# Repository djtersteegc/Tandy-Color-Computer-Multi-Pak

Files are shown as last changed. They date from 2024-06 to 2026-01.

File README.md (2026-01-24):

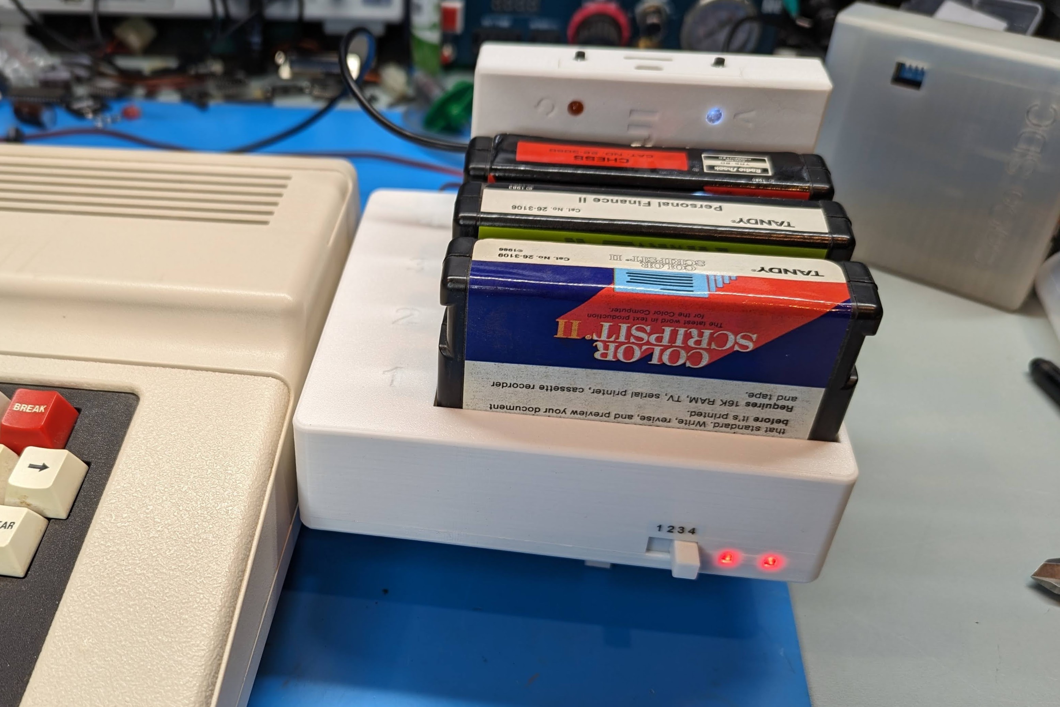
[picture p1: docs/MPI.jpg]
MPI


Inspired by the work of [TheLittleEngineers](https://github.com/TheLittleEngineers/CoCoDragon-MultiPakInterface-CC-Multi-Pak_Version_1.2), this is my respin of the Tandy 26-3024 Multi-Pak (MPI).  It's targeted at the DIY builder so the schematic is pretty much straight out of the Tandy service manual with all THT parts, minus the power section (more on that later).  The board size has been reduced as much as possible, and I added two LED's to indicate power to the MPI and Coco to minimize accidental unplugging when still powered up.  The cart slots are numbered one to four, front to back, like a real MPI, but are rotated 90 degrees so the cart labels face forward.  This was mainly done to better suit devices like the Coco Fujinet that have indicator LED's on the top of the cart and I saw Ed has done the same with his MPI variants.

For power you have a couple of different options.  You can power directly via an external 5V PSU via either a barrel jack, USB-C, or MicroUSB ports.  Or you can use a 7.5V PSU into the barrel jack and a pair of AMS1117 5V VRM's will split the power load between slots 1/2 and 3/4.  For +12V and -12V there are solder jumpers on the back to take that from the Coco1 cartridge port, but no options to provide those voltages on a Coco2 or 3.

The case is a kickstand design to save on filament costs and printing time, but does have a 35mm tall top cover to better support the carts. There are also two different top designs, one that is mostly open from the cart slots to the board, and another that is fully shrouded, but uses almost double the filament.  I personally haven't printed the latter option yet.

Schematic - https://djtersteegc.github.io/Tandy-Color-Computer-Multi-Pak/Tandy%20Color%20Computer%20Multi-Pak%20Schematic.pdf

# BOM

CSV - https://djtersteegc.github.io/Tandy-Color-Computer-Multi-Pak/Tandy%20Color%20Computer%20Multi-Pak%20BOM.csv

iBOM - https://djtersteegc.github.io/Tandy-Color-Computer-Multi-Pak/ibom.html

Google Sheet with some AliExpress links - https://docs.google.com/spreadsheets/d/16bxERXJ9wRitJPs6XrFosqCZR3fNDdbd6zl7ltthO44/edit?usp=sharing

I tend the buy most everything from China, either AliExpress of UTSource (for logic). For power, first figure out how you want to power the board and then pick the correct optional parts.  I'm assuming everyone will install the barrel jack, either for direct 5V or to feed 7.5V into the VRM's.

# Switch

The original switches I ordered from AliExpress had a 5mm high handle that was 3mm thick. That same listing is now for a 4mm high handle model which is only 2mm thick. Looking at other listings, even the ones that still show the thicker handle appear to be sending out the shorter and thinner handled model based on review pictures posted.

There are now two STL's for the switch depending on which model you get.  **MPI Switch.stl** is for the original taller/thicker one, and **MPI Switch Small Handle.stl** for the shorter/thinner one.

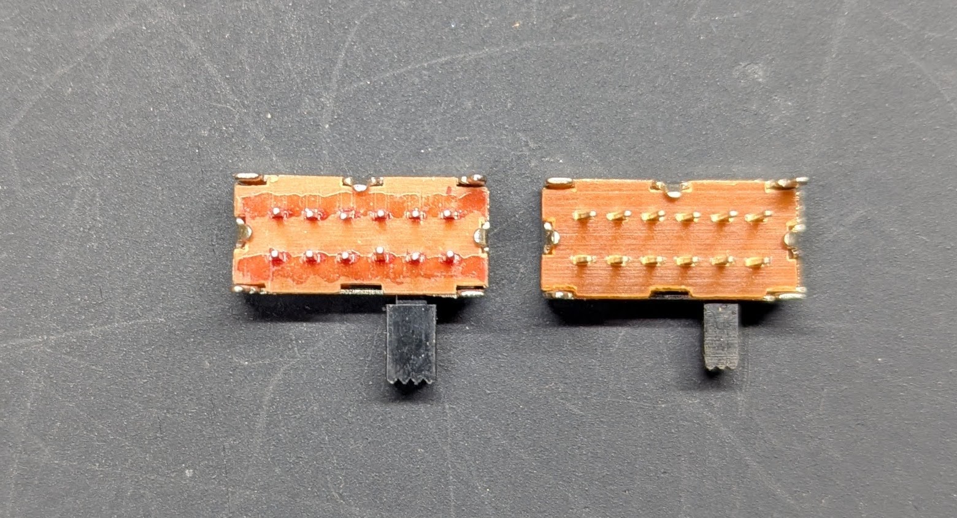
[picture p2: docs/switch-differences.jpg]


# PCB Assembly

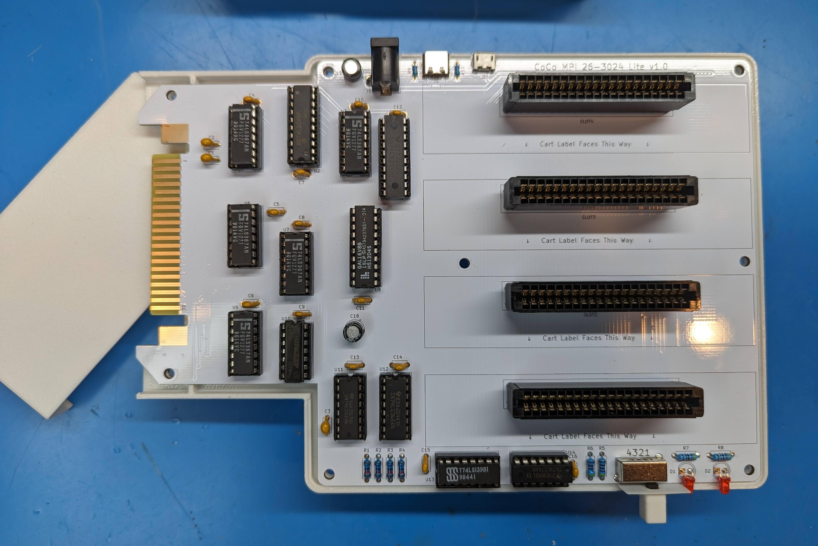
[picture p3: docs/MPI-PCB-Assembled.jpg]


# GAL Programming

U8 is a standard GAL16V8.  The programming file is available in the [GAL](GAL) directory. This should be the [newer version](https://retrocomputing.stackexchange.com/questions/477/the-tandy-trs-80-multipack-interface-mpi) that is compatible with the Coco3, but I'm unable to verify since I only have 1's and 2's to test with currently.

# 3D Printing the Case

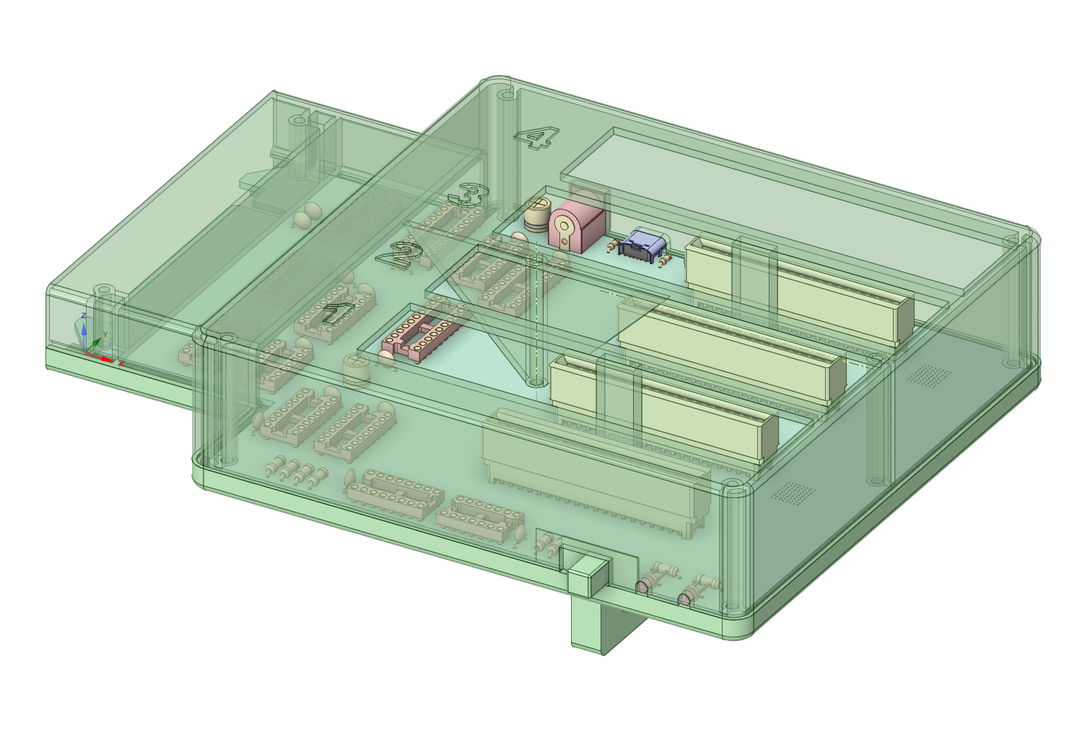
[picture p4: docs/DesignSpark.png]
DesignSpark


| Part | Filament |
| --- | --- |
| MPI Top.stl | 75g |
| MPI Bottom.stl | 62g |
| MPI Cart Top.stl | 20g |
| MPI Foot.stl | 12g |
| MPI Switch.stl | 1g |
| MPI Top Full Shroud.stl | 137g |

# Final Assembly

First screw the foot/kickstand to the bottom of the case with four [M3x10mm](https://www.aliexpress.us/item/2251832782301811.html) button head or countersunk head screws.

Then place the PCB, slide on the printed switch handle extender, place the cart top piece and then the larger top cover.  Flip over and assemble with eight M3x10mm to 14mm countersunk screws.

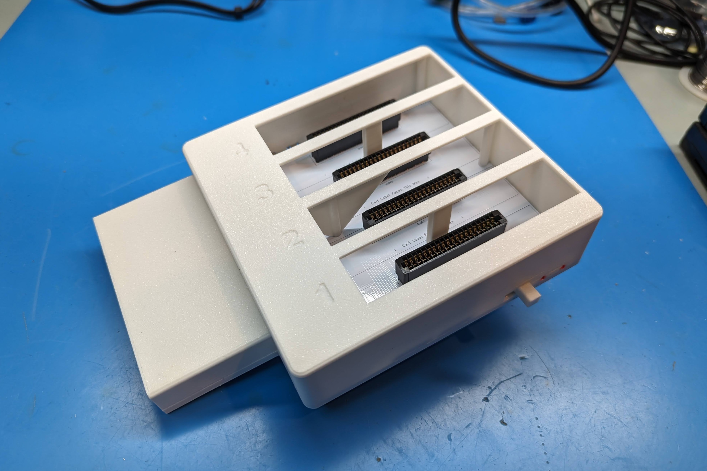
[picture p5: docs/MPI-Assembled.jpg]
MPI-Assembled


# Getting a Board to Build Your Own

Gerbers are available is you want to run your own batch. I would recommend ENIG (gold) finish since this is plugging into your cart edge connector. Otherwise if you are in the US hit my up on the Coco or FujiNet Discord (hideehoo is my username there) and if I have any extras I can drop one in the mail for $15 shipped.

# Versions

1.0 - Assembled and tested.  Initial batch of PCB's had produced had an incorrect switch footprint that required trimming of the locating tabs and the silkscreen with the slot numbering is reversed.  That has been corrected in the version 1.0 design files and gerbers in the intial upload to this repo.

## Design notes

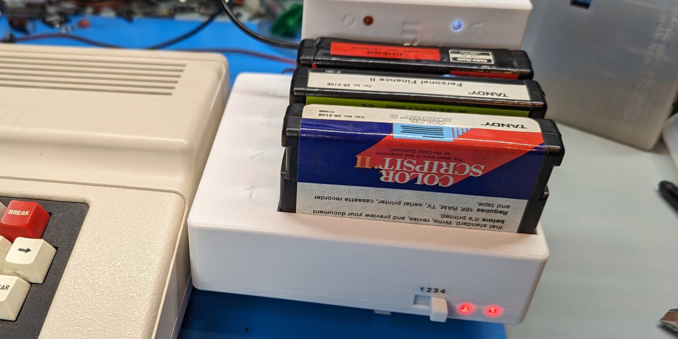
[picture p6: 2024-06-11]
docs/social.jpg

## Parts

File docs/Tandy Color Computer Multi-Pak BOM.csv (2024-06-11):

Reference | Value | Datasheet | Footprint | Qty | DNP
C1,C2 | 68pF | ~ | Capacitor_THT:C_Disc_D4.7mm_W2.5mm_P5.00mm | 2
C3 | 220pF | ~ | Capacitor_THT:C_Disc_D4.7mm_W2.5mm_P5.00mm | 1
C4,C5,C6,C7,C8,C9,C10,C11,C12,C13,C14,C15,C16 | 0.1uF | ~ | Capacitor_THT:C_Disc_D4.7mm_W2.5mm_P5.00mm | 13
C17,C20,C21,C22 | 22uf 10V | ~ | Capacitor_Tantalum_SMD:CP_EIA-3528-12_Kemet-T_Pad1.50x2.35mm_HandSolder | 4
C18,C19 | 100uF 16V | ~ | Capacitor_THT:CP_Radial_D6.3mm_P2.50mm | 2
D1,D2 | LED | ~ | LED_THT:LED_D3.0mm | 2
H1,H2,H3,H4,H5,H6,H7,H8 | MountingHole | ~ | MountingHole:MountingHole_3.2mm_M3 | 8
J1 | Barrel_Jack | ~ | Connector_BarrelJack:BarrelJack_Horizontal | 1
J2 | MICRO USB | ~ | RAHMB20AUETR:SWITCHCRAFT_RAHMB20AUETR | 1
J4 | USB-C |  | USB4125_GF_A:GCT_USB4125-GF-A_REVA2 | 1
JP1,JP2 | Plug / Reg | ~ | Jumper:SolderJumper-3_P1.3mm_Open_Pad1.0x1.5mm_NumberLabels | 2
JP3 | +12V | ~ | Jumper:SolderJumper-2_P1.3mm_Open_RoundedPad1.0x1.5mm | 1
JP4 | -12V | ~ | Jumper:SolderJumper-2_P1.3mm_Open_RoundedPad1.0x1.5mm | 1
P1 | PCB EDGE |  | Tersteeg:CoCo 40p PCB Cart Connector | 1
P2 | SLOT1 |  | Tersteeg:Coco 40p Cart Edge Connector | 1
P3 | SLOT2 |  | Tersteeg:Coco 40p Cart Edge Connector | 1
P4 | SLOT3 |  | Tersteeg:Coco 40p Cart Edge Connector | 1
P5 | SLOT4 |  | Tersteeg:Coco 40p Cart Edge Connector | 1
R1,R2,R3,R4 | 10K | ~ | Resistor_THT:R_Axial_DIN0207_L6.3mm_D2.5mm_P7.62mm_Horizontal | 4
R5,R6 | 4K7 | ~ | Resistor_THT:R_Axial_DIN0207_L6.3mm_D2.5mm_P7.62mm_Horizontal | 2
R7,R8 | 470R | ~ | Resistor_THT:R_Axial_DIN0207_L6.3mm_D2.5mm_P7.62mm_Horizontal | 2
R9,R10 | 5.1K | ~ | Resistor_THT:R_Axial_DIN0204_L3.6mm_D1.6mm_P5.08mm_Horizontal | 2
SW1 | ~ |  | Tersteeg:SK24D02VG4 2P4T Slide Switch | 1
U1,U3,U6,U7,U9 | 74LS367 | http://www.ti.com/lit/gpn/sn74LS367 | Package_DIP:DIP-16_W7.62mm_Socket | 5
U2 | 74LS245 | http://www.ti.com/lit/gpn/sn74LS245 | Package_DIP:DIP-20_W7.62mm_Socket | 1
U4 | 74LS374 | http://www.ti.com/lit/gpn/sn74LS374 | Package_DIP:DIP-20_W7.62mm_Socket | 1
U8 | GAL16V8 |  | Package_DIP:DIP-20_W7.62mm_Socket | 1
U10 | 74LS30 | http://www.ti.com/lit/gpn/sn74LS30 | Package_DIP:DIP-14_W7.62mm_Socket | 1
U11 | 74LS153 | http://www.ti.com/lit/gpn/sn74LS153 | Package_DIP:DIP-16_W7.62mm_Socket | 1
U12 | 74LS368 | http://www.ti.com/lit/gpn/sn74LS368 | Package_DIP:DIP-16_W7.62mm_Socket | 1
U13 | 74LS139 | http://www.ti.com/lit/ds/symlink/sn74ls139a.pdf | Package_DIP:DIP-16_W7.62mm_Socket | 1
U14 | 74LS74 | 74xx/74hc_hct74.pdf | Package_DIP:DIP-14_W7.62mm_Socket | 1
U15,U16 | AMS1117-5.0 | http://www.advanced-monolithic.com/pdf/ds1117.pdf | Tersteeg:SOT-223-3_TabPin2_Ext_Thermal | 2

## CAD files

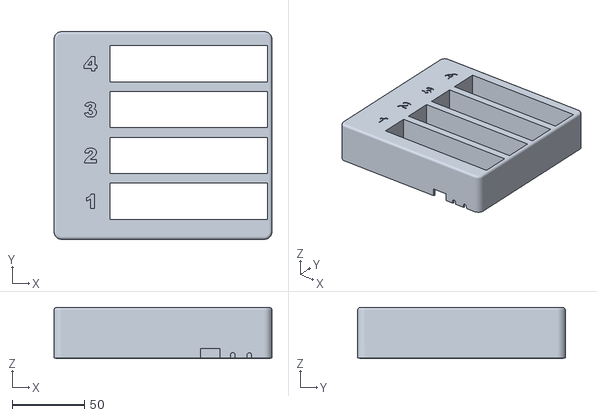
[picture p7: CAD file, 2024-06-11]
3D/STL/MPI Top Full Shroud.stl
150.9 x 143.9 x 35.6

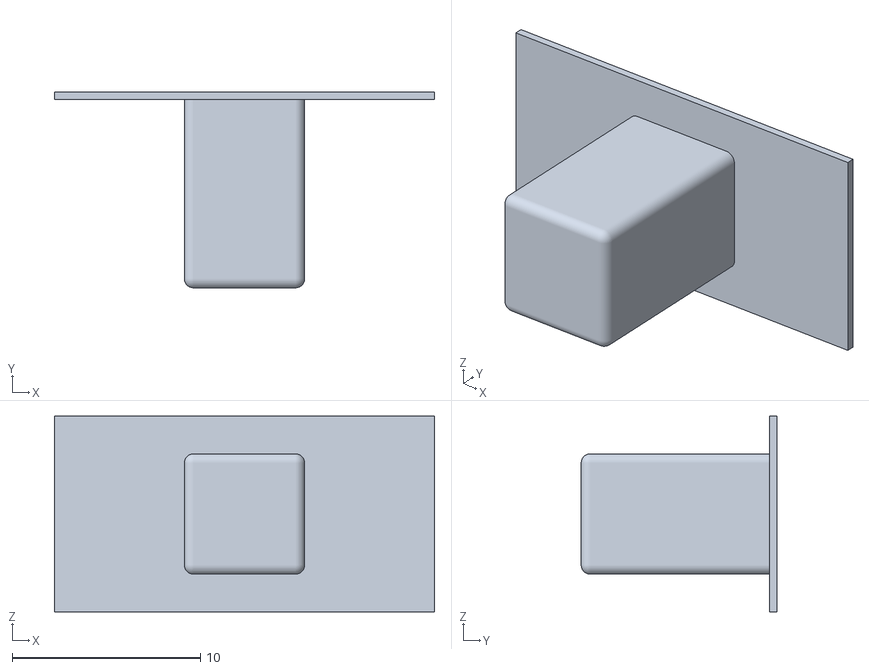
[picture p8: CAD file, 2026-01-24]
3D/STL/MPI Switch Small Handle.stl
20.2 x 10.4 x 10.4

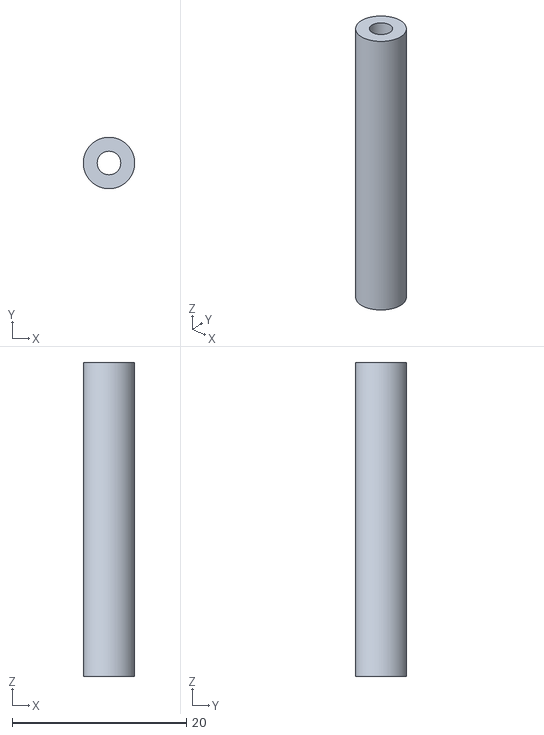
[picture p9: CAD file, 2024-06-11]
3D/STL/M3 x 38mm Standoff.stl
5.90 x 5.90 x 36.0

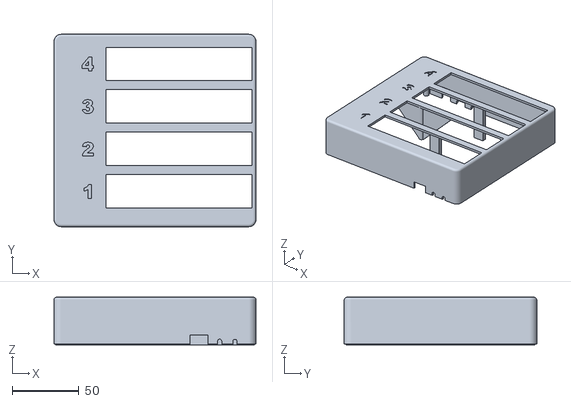
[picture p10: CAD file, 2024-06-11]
3D/STL/MPI Top.stl
150.9 x 143.9 x 35.6

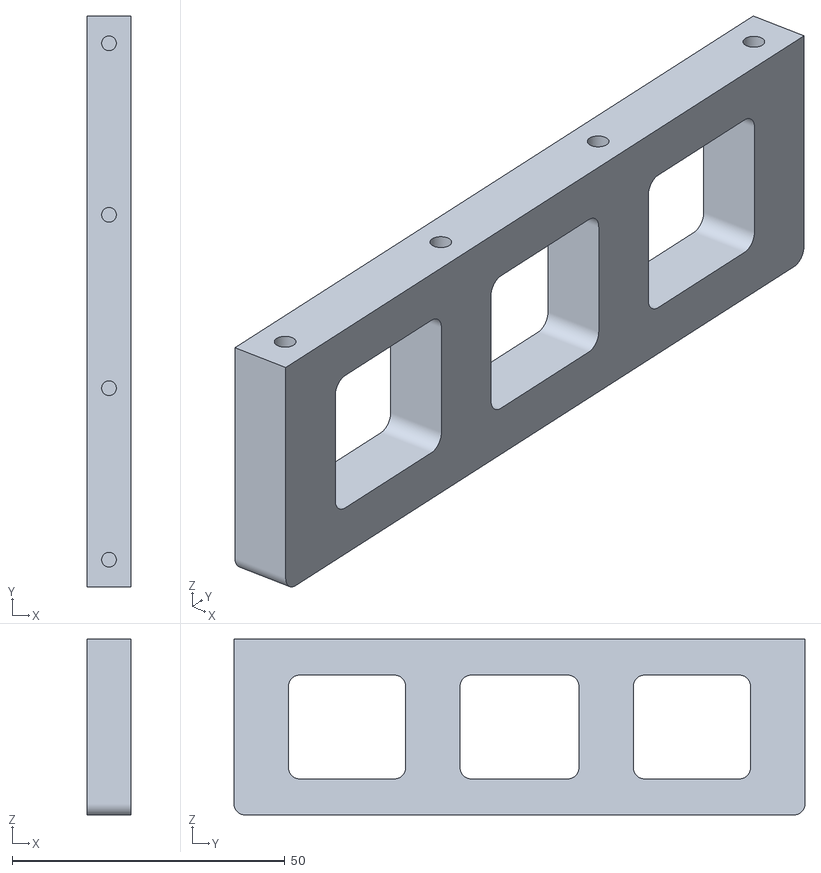
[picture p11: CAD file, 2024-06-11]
3D/STL/MPI Foot.stl
8.00 x 104.6 x 32.2

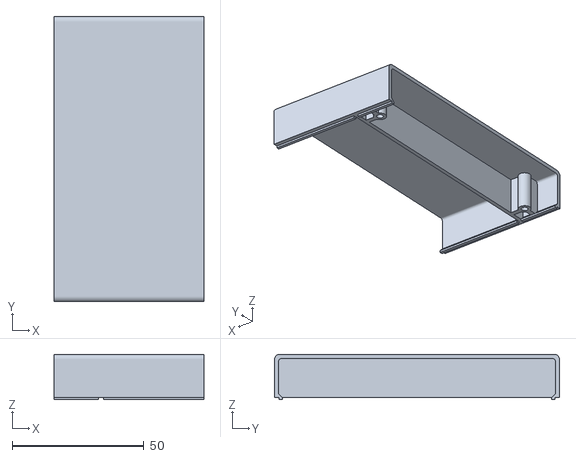
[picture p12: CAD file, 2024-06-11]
3D/STL/MPI Cart Top.stl
56.8 x 108.0 x 17.2

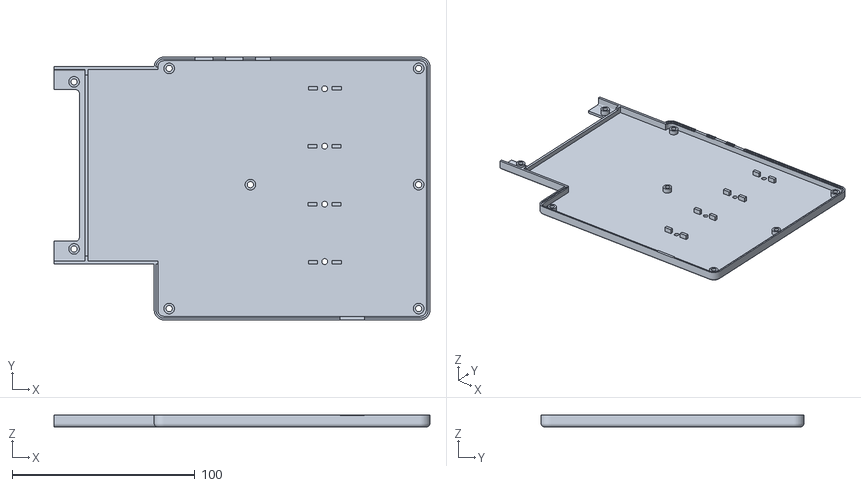
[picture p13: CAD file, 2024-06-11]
3D/STL/MPI Bottom.stl
205.8 x 143.9 x 6.60

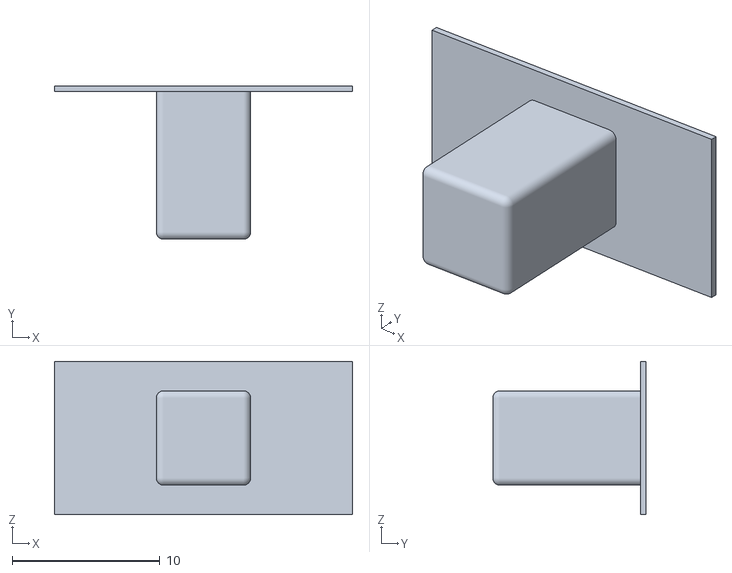
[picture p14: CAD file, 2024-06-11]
3D/STL/MPI Switch.stl
20.2 x 10.4 x 10.4

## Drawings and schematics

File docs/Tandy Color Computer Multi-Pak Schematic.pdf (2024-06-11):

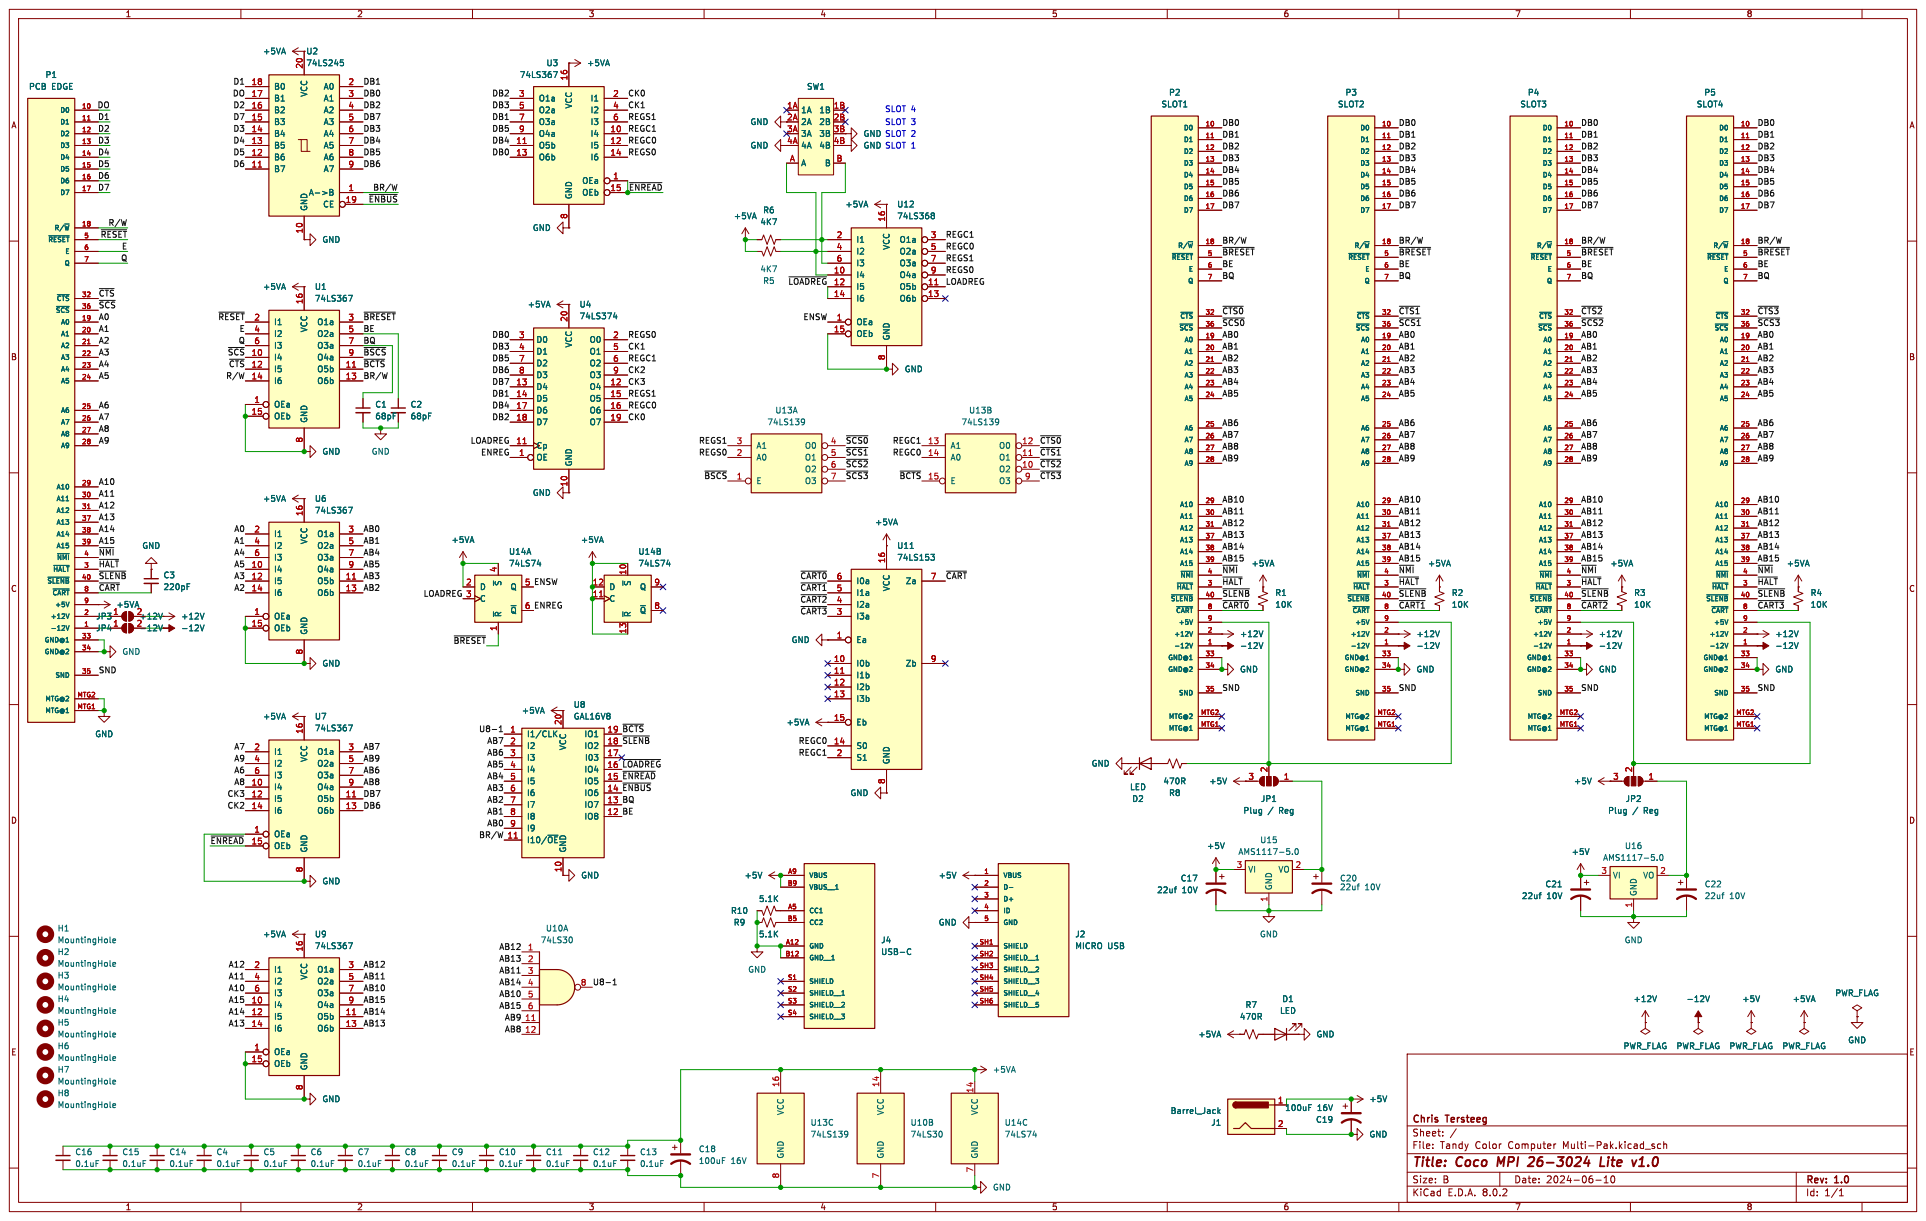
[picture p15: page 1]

~{CTS0} SLOT 2 SLOT 1 SLOT 3 SLOT 4

H2 MountingHole H5 MountingHole H1 MountingHole H3 MountingHole H4 MountingHole

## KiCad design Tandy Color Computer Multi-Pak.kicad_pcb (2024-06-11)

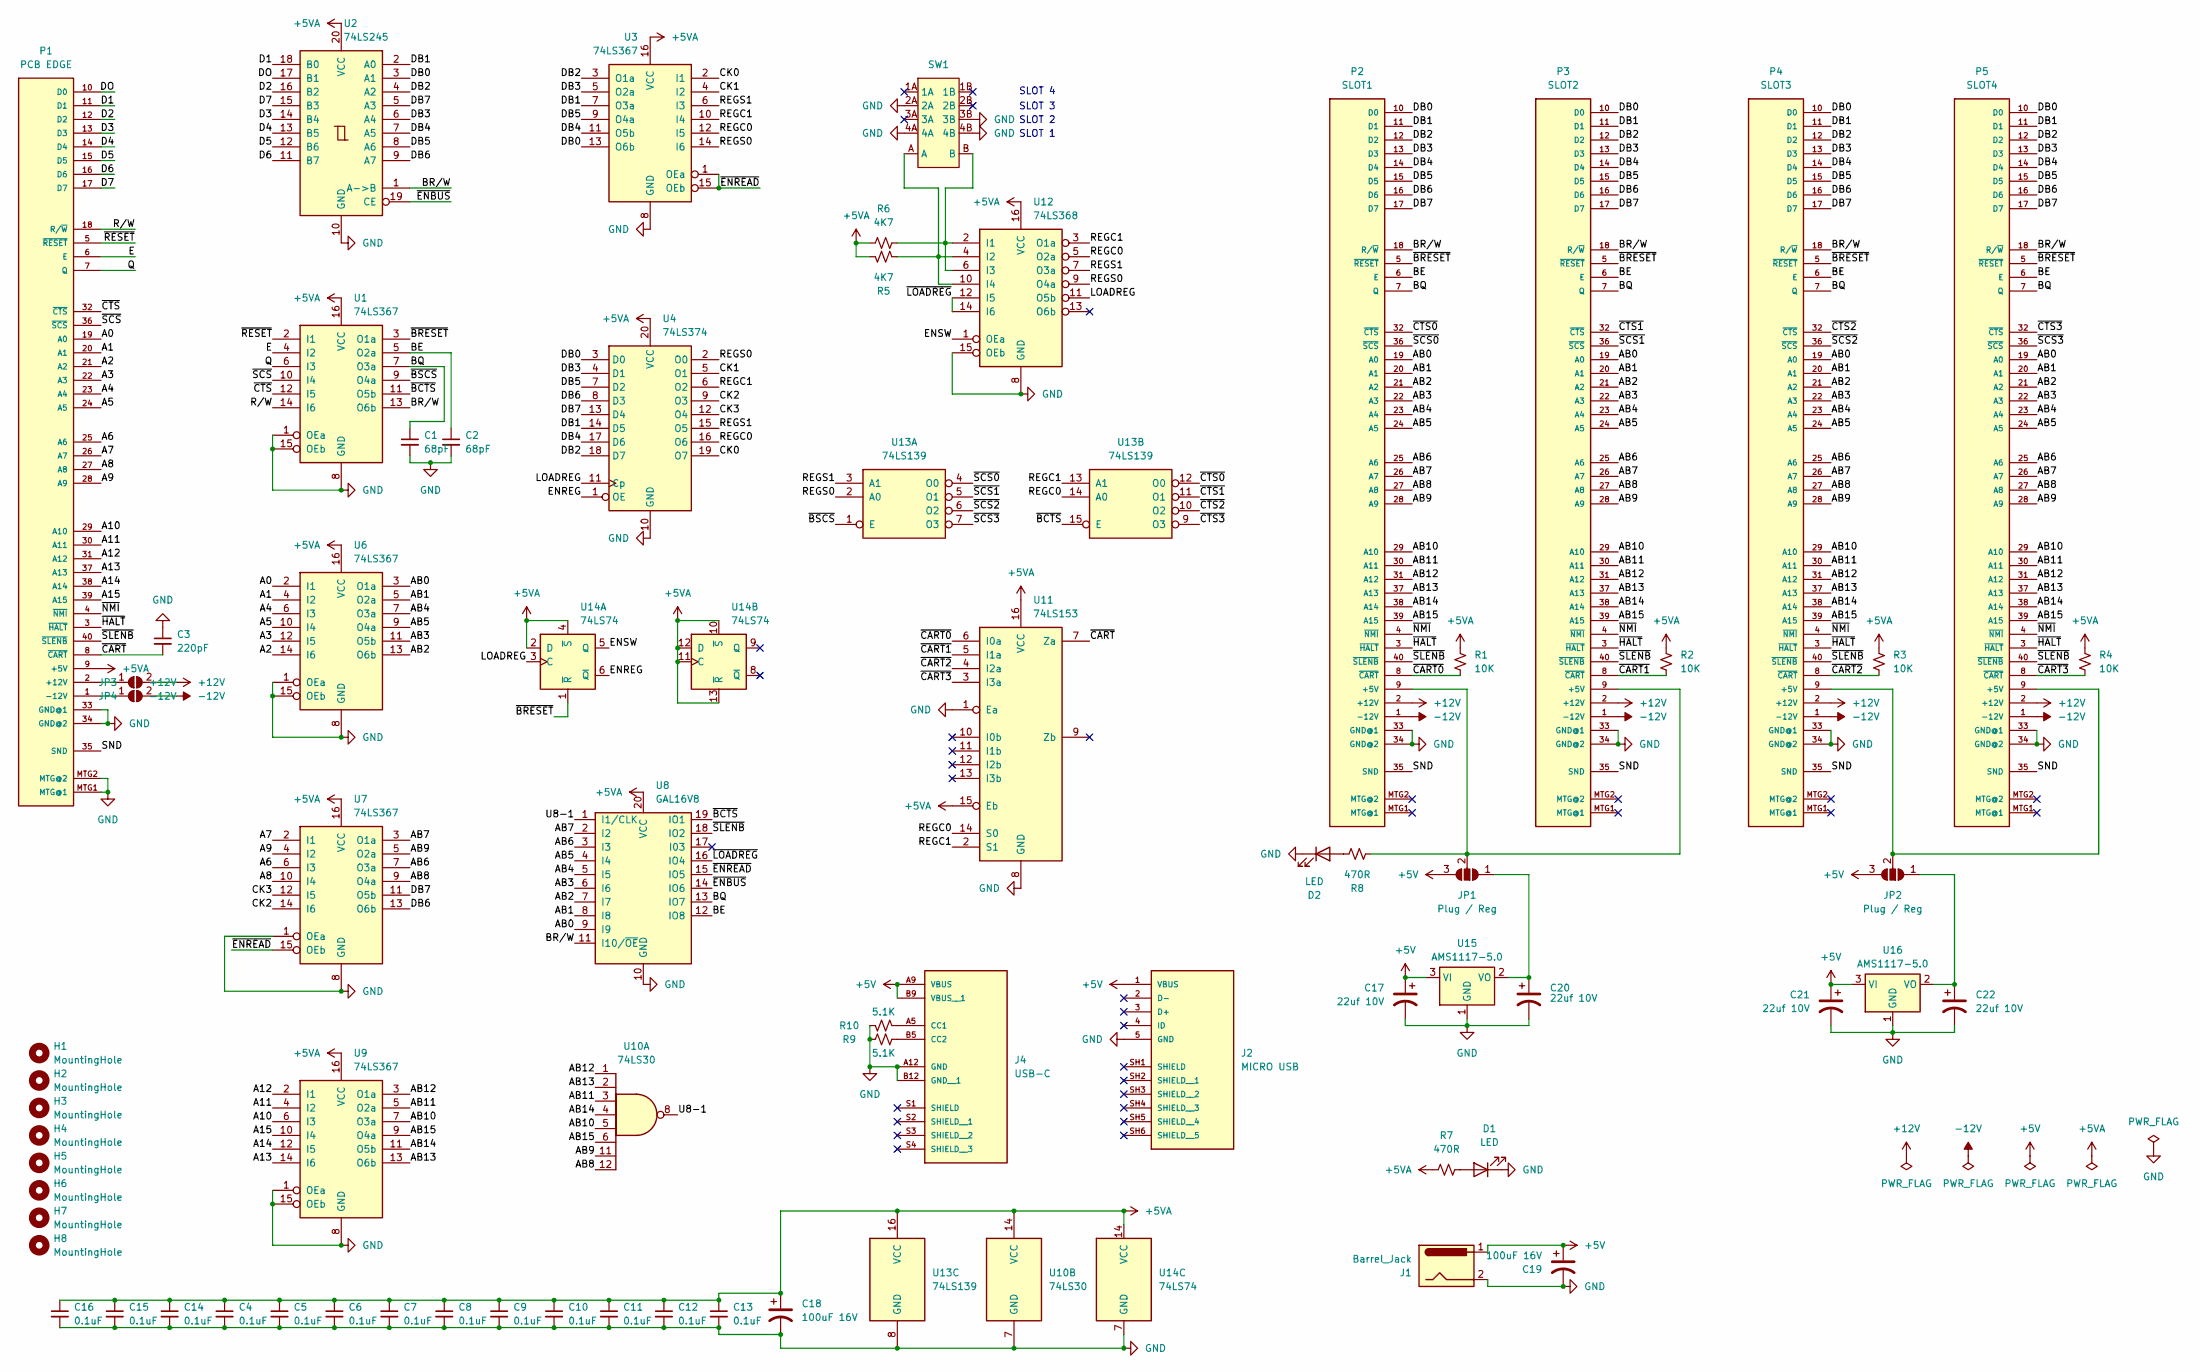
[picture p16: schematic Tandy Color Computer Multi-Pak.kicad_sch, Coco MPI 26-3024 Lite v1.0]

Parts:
C1, C2: 68pF; C_Disc_D4.7mm_W2.5mm_P5.00mm
C3: 220pF; C_Disc_D4.7mm_W2.5mm_P5.00mm
C4, C5, C6, C7, C8, C9, C10, C11, C12, C13, C14, C15, C16: 0.1uF; C_Disc_D4.7mm_W2.5mm_P5.00mm
C17, C20, C21, C22: 22uf 10V; CP_EIA-3528-12_Kemet-T_Pad1.50x2.35mm_HandSolder
C18, C19: 100uF 16V; CP_Radial_D6.3mm_P2.50mm
D1, D2: LED; LED_D3.0mm
H1, H2, H3, H4, H5, H6, H7, H8: MountingHole; MountingHole_3.2mm_M3
J1: Barrel_Jack; BarrelJack_Horizontal
J2: MICRO USB; SWITCHCRAFT_RAHMB20AUETR; PARTREV A
J4: USB-C; GCT_USB4125-GF-A_REVA2; PARTREV Rev A2
JP1, JP2: Plug / Reg; SolderJumper-3_P1.3mm_Open_Pad1.0x1.5mm_NumberLabels
JP3: +12V; SolderJumper-2_P1.3mm_Open_RoundedPad1.0x1.5mm
JP4: -12V; SolderJumper-2_P1.3mm_Open_RoundedPad1.0x1.5mm
P1: PCB EDGE; CoCo 40p PCB Cart Connector
P2: SLOT1; Coco 40p Cart Edge Connector
P3: SLOT2; Coco 40p Cart Edge Connector
P4: SLOT3; Coco 40p Cart Edge Connector
P5: SLOT4; Coco 40p Cart Edge Connector
R1, R2, R3, R4: 10K; R_Axial_DIN0207_L6.3mm_D2.5mm_P7.62mm_Horizontal
R5, R6: 4K7; R_Axial_DIN0207_L6.3mm_D2.5mm_P7.62mm_Horizontal
R7, R8: 470R; R_Axial_DIN0207_L6.3mm_D2.5mm_P7.62mm_Horizontal
R9, R10: 5.1K; R_Axial_DIN0204_L3.6mm_D1.6mm_P5.08mm_Horizontal
SW1: SK24D02VG4 2P4T Slide Switch
U1, U3, U6, U7, U9: 74LS367; DIP-16_W7.62mm_Socket
U2: 74LS245; DIP-20_W7.62mm_Socket
U4: 74LS374; DIP-20_W7.62mm_Socket
U8: GAL16V8; DIP-20_W7.62mm_Socket
U10: 74LS30; DIP-14_W7.62mm_Socket
U11: 74LS153; DIP-16_W7.62mm_Socket
U12: 74LS368; DIP-16_W7.62mm_Socket
U13: 74LS139; DIP-16_W7.62mm_Socket
U14: 74LS74; DIP-14_W7.62mm_Socket
U15, U16: AMS1117-5.0; SOT-223-3_TabPin2_Ext_Thermal

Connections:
+5V: C17.1, C19.1, C21.1, J1.1, J2.1 (VBUS), J4.A9 (VBUS), J4.B9 (VBUS__1), JP1.3 (B), JP2.3 (B), U15.3 (VI), U16.3 (VI)
+5VA: C4.1, C5.1, C6.1, C7.1, C8.1, C9.1, C10.1, C11.1, C12.1, C13.1, C14.1, C15.1, C16.1, C18.1, P1.9 (+5V), R1.1, R2.1, R3.1, R4.1, R5.1, R6.1, R7.1, U1.16 (VCC), U2.20 (VCC), U3.16 (VCC), U4.20 (VCC), U6.16 (VCC), U7.16 (VCC), U8.20 (VCC), U9.16 (VCC), U10.14 (VCC), U11.15 (Eb), U11.16 (VCC), U12.16 (VCC), U13.16 (VCC), U14.2 (D), U14.4 (~S), U14.10 (~S), U14.11 (C), U14.12 (D), U14.13 (~R), U14.14 (VCC)
+12V: JP3.2 (B), P2.2 (+12V), P3.2 (+12V), P4.2 (+12V), P5.2 (+12V)
-12V: JP4.2 (B), P2.1 (-12V), P3.1 (-12V), P4.1 (-12V), P5.1 (-12V)
/A0: P1.19 (A0), U6.2 (I1)
/A1: P1.20 (A1), U6.4 (I2)
/A2: P1.21 (A2), U6.14 (I6)
/A3: P1.22 (A3), U6.12 (I5)
/A4: P1.23 (A4), U6.6 (I3)
/A5: P1.24 (A5), U6.10 (I4)
/A6: P1.25 (A6), U7.6 (I3)
/A7: P1.26 (A7), U7.2 (I1)
/A8: P1.27 (A8), U7.10 (I4)
/A9: P1.28 (A9), U7.4 (I2)
/A10: P1.29 (A10), U9.6 (I3)
/A11: P1.30 (A11), U9.4 (I2)
/A12: P1.31 (A12), U9.2 (I1)
/A13: P1.37 (A13), U9.14 (I6)
/A14: P1.38 (A14), U9.12 (I5)
/A15: P1.39 (A15), U9.10 (I4)
/AB0: P2.19 (A0), P3.19 (A0), P4.19 (A0), P5.19 (A0), U6.3 (O1a), U8.9 (I9)
/AB1: P2.20 (A1), P3.20 (A1), P4.20 (A1), P5.20 (A1), U6.5 (O2a), U8.8 (I8)
/AB2: P2.21 (A2), P3.21 (A2), P4.21 (A2), P5.21 (A2), U6.13 (O6b), U8.7 (I7)
/AB3: P2.22 (A3), P3.22 (A3), P4.22 (A3), P5.22 (A3), U6.11 (O5b), U8.6 (I6)
/AB4: P2.23 (A4), P3.23 (A4), P4.23 (A4), P5.23 (A4), U6.7 (O3a), U8.5 (I5)
/AB5: P2.24 (A5), P3.24 (A5), P4.24 (A5), P5.24 (A5), U6.9 (O4a), U8.4 (I4)
/AB6: P2.25 (A6), P3.25 (A6), P4.25 (A6), P5.25 (A6), U7.7 (O3a), U8.3 (I3)
/AB7: P2.26 (A7), P3.26 (A7), P4.26 (A7), P5.26 (A7), U7.3 (O1a), U8.2 (I2)
/AB8: P2.27 (A8), P3.27 (A8), P4.27 (A8), P5.27 (A8), U7.9 (O4a), U10.12
/AB9: P2.28 (A9), P3.28 (A9), P4.28 (A9), P5.28 (A9), U7.5 (O2a), U10.11
/AB10: P2.29 (A10), P3.29 (A10), P4.29 (A10), P5.29 (A10), U9.7 (O3a), U10.5
/AB11: P2.30 (A11), P3.30 (A11), P4.30 (A11), P5.30 (A11), U9.5 (O2a), U10.3
/AB12: P2.31 (A12), P3.31 (A12), P4.31 (A12), P5.31 (A12), U9.3 (O1a), U10.1
/AB13: P2.37 (A13), P3.37 (A13), P4.37 (A13), P5.37 (A13), U9.13 (O6b), U10.2
/AB14: P2.38 (A14), P3.38 (A14), P4.38 (A14), P5.38 (A14), U9.11 (O5b), U10.4
/AB15: P2.39 (A15), P3.39 (A15), P4.39 (A15), P5.39 (A15), U9.9 (O4a), U10.6
/BE: C2.1, P2.6 (E), P3.6 (E), P4.6 (E), P5.6 (E), U1.5 (O2a), U8.12 (IO8)
/BQ: C1.1, P2.7 (Q), P3.7 (Q), P4.7 (Q), P5.7 (Q), U1.7 (O3a), U8.13 (IO7)
/BR/W: P2.18 (R/~W), P3.18 (R/~W), P4.18 (R/~W), P5.18 (R/~W), U1.13 (O6b), U2.1 (A->B), U8.11 (I10/~OE)
/CK0: U3.2 (I1), U4.19 (O7)
/CK1: U3.4 (I2), U4.5 (O1)
/CK2: U4.9 (O3), U7.14 (I6)
/CK3: U4.12 (O4), U7.12 (I5)
/D1: P1.11 (D1), U2.18 (B0)
/D2: P1.12 (D2), U2.16 (B2)
/D3: P1.13 (D3), U2.14 (B4)
/D4: P1.14 (D4), U2.13 (B5)
/D5: P1.15 (D5), U2.12 (B6)
/D6: P1.16 (D6), U2.11 (B7)
/D7: P1.17 (D7), U2.15 (B3)
/DB0: P2.10 (D0), P3.10 (D0), P4.10 (D0), P5.10 (D0), U2.3 (A1), U3.13 (O6b), U4.3 (D0)
/DB1: P2.11 (D1), P3.11 (D1), P4.11 (D1), P5.11 (D1), U2.2 (A0), U3.7 (O3a), U4.14 (D5)
/DB2: P2.12 (D2), P3.12 (D2), P4.12 (D2), P5.12 (D2), U2.4 (A2), U3.3 (O1a), U4.18 (D7)
/DB3: P2.13 (D3), P3.13 (D3), P4.13 (D3), P5.13 (D3), U2.6 (A4), U3.5 (O2a), U4.4 (D1)
/DB4: P2.14 (D4), P3.14 (D4), P4.14 (D4), P5.14 (D4), U2.7 (A5), U3.11 (O5b), U4.17 (D6)
/DB5: P2.15 (D5), P3.15 (D5), P4.15 (D5), P5.15 (D5), U2.8 (A6), U3.9 (O4a), U4.7 (D2)
/DB6: P2.16 (D6), P3.16 (D6), P4.16 (D6), P5.16 (D6), U2.9 (A7), U4.8 (D3), U7.13 (O6b)
/DB7: P2.17 (D7), P3.17 (D7), P4.17 (D7), P5.17 (D7), U2.5 (A3), U4.13 (D4), U7.11 (O5b)
/DO: P1.10 (D0), U2.17 (B1)
/E: P1.6 (E), U1.4 (I2)
/ENREG: U4.1 (OE), U14.6 (~Q)
/ENSW: U12.1 (OEa), U14.5 (Q)
/LOADREG: U4.11 (Cp), U12.11 (O5b), U14.3 (C)
/Q: P1.7 (Q), U1.6 (I3)
/REGC0: U3.12 (I5), U4.16 (O6), U11.14 (S0), U12.5 (O2a), U13.14 (A0)
/REGC1: U3.10 (I4), U4.6 (O2), U11.2 (S1), U12.3 (O1a), U13.13 (A1)
/REGS0: U3.14 (I6), U4.2 (O0), U12.9 (O4a), U13.2 (A0)
/REGS1: U3.6 (I3), U4.15 (O5), U12.7 (O3a), U13.3 (A1)
/R/W: P1.18 (R/~W), U1.14 (I6)
/SND: P1.35 (SND), P2.35 (SND), P3.35 (SND), P4.35 (SND), P5.35 (SND)
/U8-1: U8.1 (I1/CLK), U10.8
/~BCTS: U1.11 (O5b), U8.19 (IO1), U13.15 (E)
/~BRESET: P2.5 (~RESET), P3.5 (~RESET), P4.5 (~RESET), P5.5 (~RESET), U1.3 (O1a), U14.1 (~R)
/~BSCS: U1.9 (O4a), U13.1 (E)
/~CART0: P2.8 (~CART), R1.2, U11.6 (I0a)
/~CART1: P3.8 (~CART), R2.2, U11.5 (I1a)
/~CART2: P4.8 (~CART), R3.2, U11.4 (I2a)
/~CART3: P5.8 (~CART), R4.2, U11.3 (I3a)
/~CART: C3.2, P1.8 (~CART), U11.7 (Za)
/~CTS0: P2.32 (~CTS), U13.12 (O0)
/~CTS1: P3.32 (~CTS), U13.11 (O1)
/~CTS2: P4.32 (~CTS), U13.10 (O2)
/~CTS3: P5.32 (~CTS), U13.9 (O3)
/~CTS: P1.32 (~CTS), U1.12 (I5)
/~ENBUS: U2.19 (CE), U8.14 (IO6)
/~ENREAD: U3.1 (OEa), U3.15 (OEb), U7.15 (OEb), U8.15 (IO5)
/~HALT: P1.3 (~HALT), P2.3 (~HALT), P3.3 (~HALT), P4.3 (~HALT), P5.3 (~HALT)
/~LOADREG: U8.16 (IO4), U12.12 (I5), U12.14 (I6)
/~NMI: P1.4 (~NMI), P2.4 (~NMI), P3.4 (~NMI), P4.4 (~NMI), P5.4 (~NMI)
/~RESET: P1.5 (~RESET), U1.2 (I1)
/~SCS0: P2.36 (~SCS), U13.4 (O0)
/~SCS1: P3.36 (~SCS), U13.5 (O1)
/~SCS2: P4.36 (~SCS), U13.6 (O2)
/~SCS3: P5.36 (~SCS), U13.7 (O3)
/~SCS: P1.36 (~SCS), U1.10 (I4)
/~SLENB: P1.40 (~SLENB), P2.40 (~SLENB), P3.40 (~SLENB), P4.40 (~SLENB), P5.40 (~SLENB), U8.18 (IO2)
GND: C1.2, C2.2, C3.1, C4.2, C5.2, C6.2, C7.2, C8.2, C9.2, C10.2, C11.2, C12.2, C13.2, C14.2, C15.2, C16.2, C17.2, C18.2, C19.2, C20.2, C21.2, C22.2, D1.1 (K), D2.1 (K), J1.2, J2.5 (GND), J4.A12 (GND), J4.B12 (GND__1), P1.33 (GND@1), P1.34 (GND@2), P1.MTG1 (MTG@1), P1.MTG2 (MTG@2), P2.33 (GND@1), P2.34 (GND@2), P3.33 (GND@1), P3.34 (GND@2), P4.33 (GND@1), P4.34 (GND@2), P5.33 (GND@1), P5.34 (GND@2), R9.2, R10.2, SW1.2A, SW1.3B, SW1.4A, SW1.4B, U1.1 (OEa), U1.8 (GND), U1.15 (OEb), U2.10 (GND), U3.8 (GND), U4.10 (GND), U6.1 (OEa), U6.8 (GND), U6.15 (OEb), U7.1 (OEa), U7.8 (GND), U8.10 (GND), U9.1 (OEa), U9.8 (GND), U9.15 (OEb), U10.7 (GND), U11.1 (Ea), U11.8 (GND), U12.8 (GND), U12.15 (OEb), U13.8 (GND), U14.7 (GND), U15.1 (GND), U16.1 (GND)
unnamed: D1.2 (A), R7.2
unnamed: D2.2 (A), R8.2
unnamed: J4.A5 (CC1), R10.1
unnamed: J4.B5 (CC2), R9.1
unnamed: C20.1, JP1.1 (A), U15.2 (VO)
unnamed: JP1.2 (C), P2.9 (+5V), P3.9 (+5V), R8.1
unnamed: C22.1, JP2.1 (A), U16.2 (VO)
unnamed: JP2.2 (C), P4.9 (+5V), P5.9 (+5V)
unnamed: JP3.1 (A), P1.2 (+12V)
unnamed: JP4.1 (A), P1.1 (-12V)
unnamed: R6.2, SW1.B, U12.2 (I1), U12.6 (I3)
unnamed: R5.2, SW1.A, U12.4 (I2), U12.10 (I4)

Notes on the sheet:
SLOT 3
SLOT 4
SLOT 2
SLOT 1

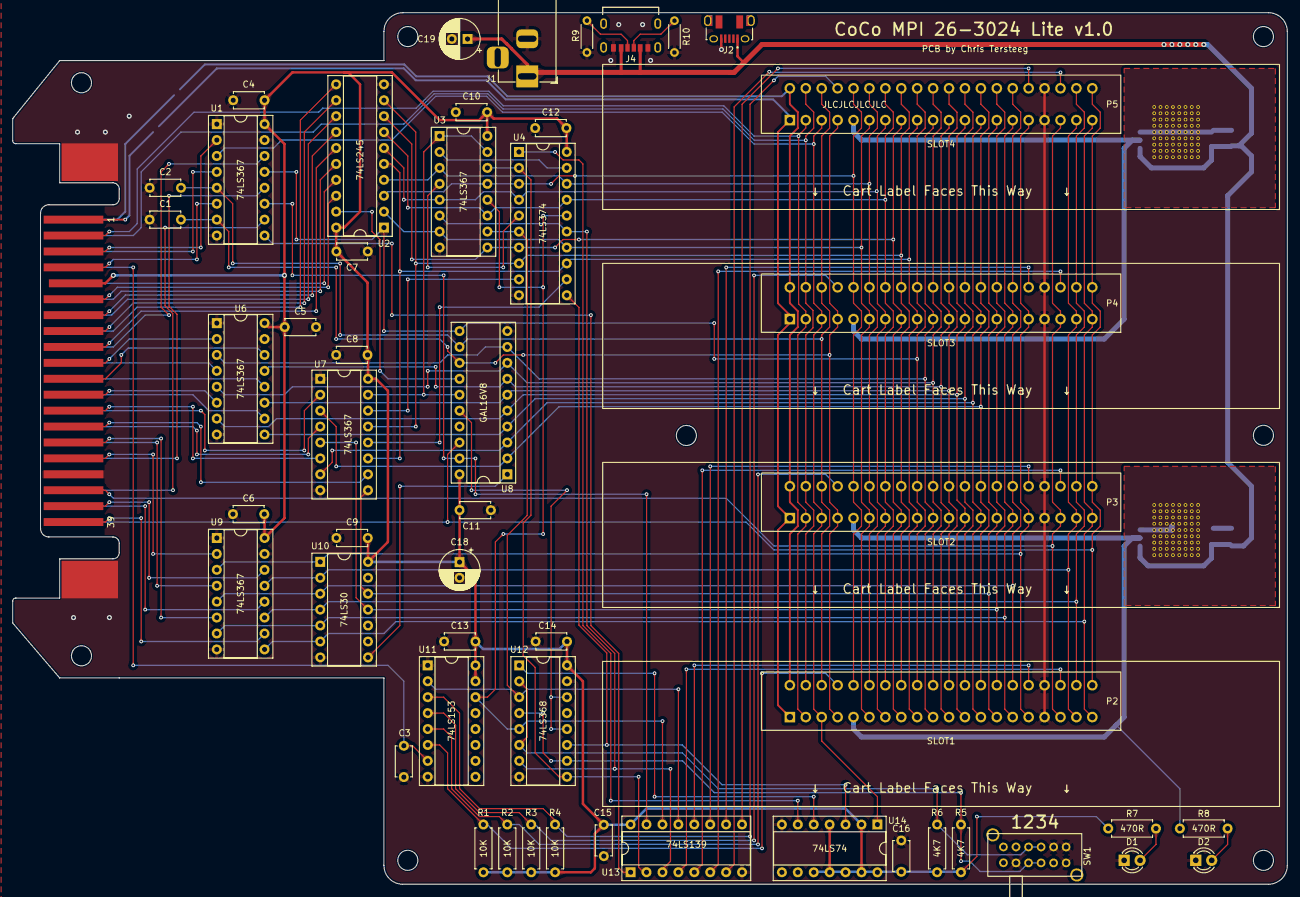
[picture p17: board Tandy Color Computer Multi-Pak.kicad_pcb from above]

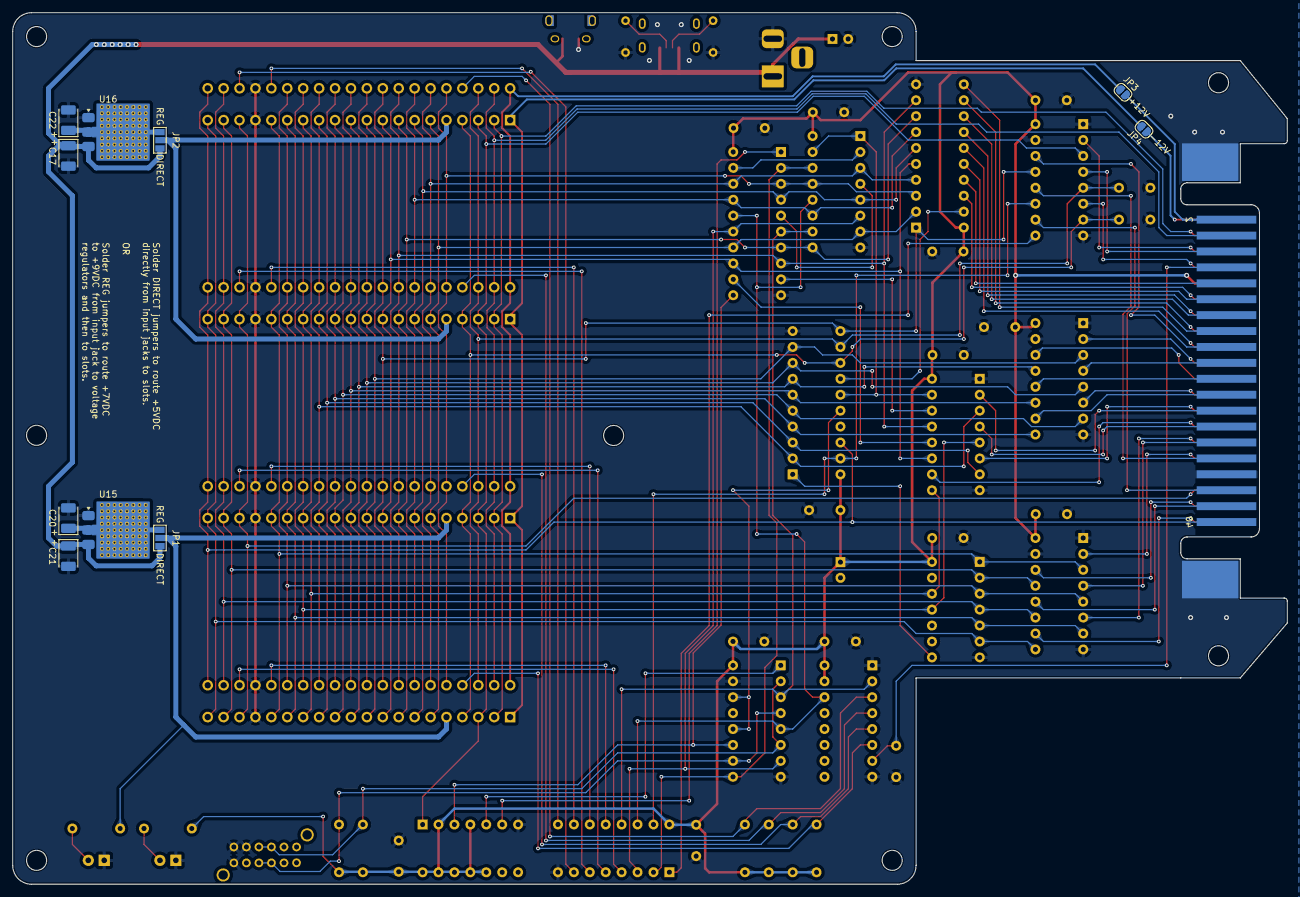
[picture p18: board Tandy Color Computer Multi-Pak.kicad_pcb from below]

Board: 2 copper layers, 203.4 x 139.1 mm, 70 parts (10 on the bottom side), 109 nets.

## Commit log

2024-06-11 Initial 1.0 version
    [M3 x 38mm Standoff.stl, MPI Bottom.stl, MPI Cart Top.stl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]
2026-01-24 Update docs for assembly, add alternative switch model
    [MPI Switch Small Handle.stl]
